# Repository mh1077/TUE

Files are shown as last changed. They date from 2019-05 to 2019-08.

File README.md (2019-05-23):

# TUE
Tochteruhrempfänger für MRClock

Dieser Empfänger verarbeitet die Multicast Telegramme eines MRClock Zeitzeichenservers. Aus einer LiPo Zelle (4.2 V) werden die 12 Volt bzw. 24 Volt für die Tochteruhren, auch Nebenuhren genannt, generiert und gleichzeitig der Empfänger (ESP8266) versorgt. Eine Ladeschaltung läd aus einer 5V Versorgung (USB oder Steckernetzteil) die LiPo Zelle.  

Eine Abschaltung bei niedriger LiPo Zellenspannung (ab ca. 3.1V) ist eingebaut. Der Empfänger behält die an der Tochteruhr angezeigte Uhrzeit gespeichert und läuft während dem Ladevorgang ab ca. 3.6V wieder los.

Ein TUE kann auch die Normalzeit mit NTP empfangen. Das funktioniert so. Wird ca. 6 Minuten nach der Konfiguration des Empfängers kein gültiges MRClock Telegramm empfangen, wird die Normalzeit angezeigt. Die Normalzeit wird auch angezeigt, wenn 24 Stunden kein gültiges MRClock Telegramm empfangen wurde. Es wird die MEZ mit automatischer Sommer-/Winterzeitumstellung angezeigt. Wird der Empfänger neu gestartet, sei es durch Reset oder Einschalten, wird nach ca. 6 Minuten auf NTP umgestellt wenn kein MRClock Telegramm empfangen wurde.

Das Projekt enthält die EAGLE Dateien, den Arduino Sourcecode und eine Bedienungsanleitung für den Tochteruhrempfänger.

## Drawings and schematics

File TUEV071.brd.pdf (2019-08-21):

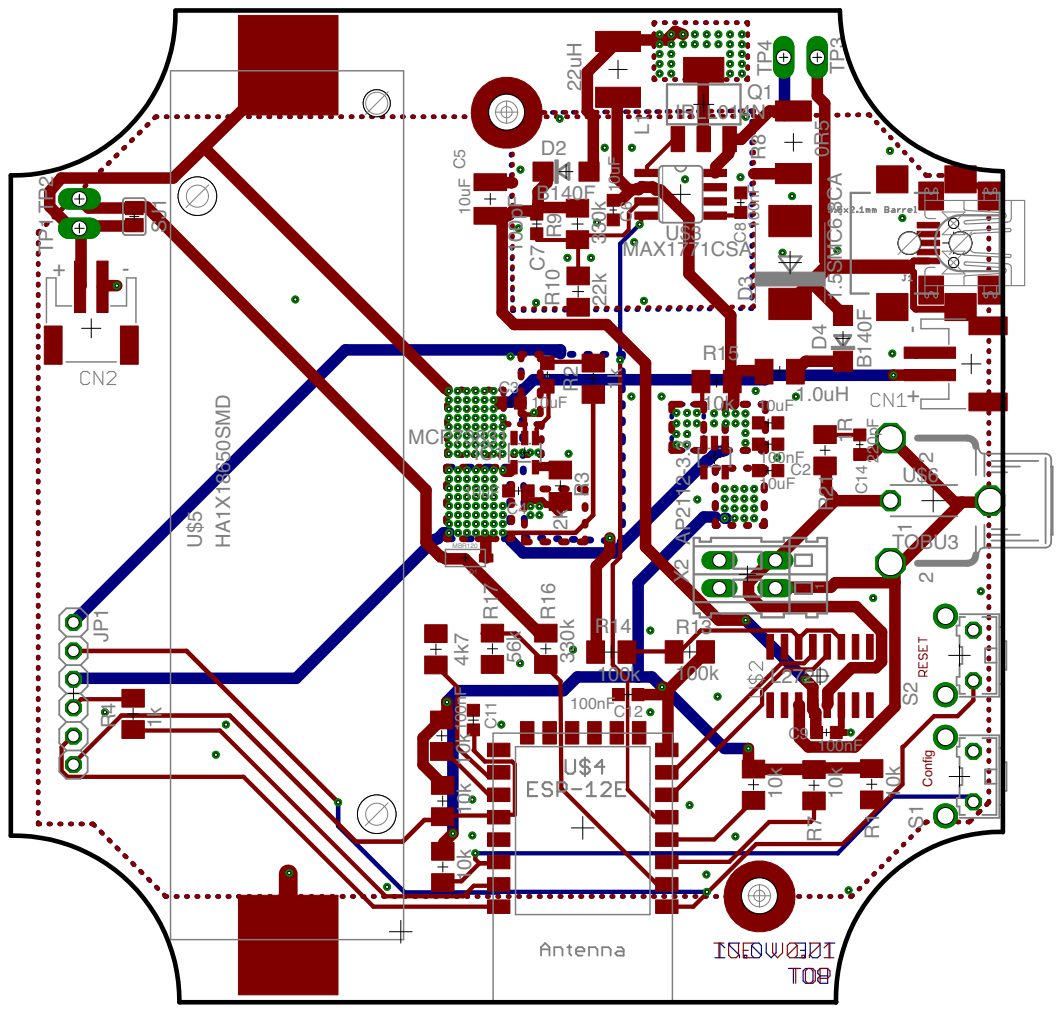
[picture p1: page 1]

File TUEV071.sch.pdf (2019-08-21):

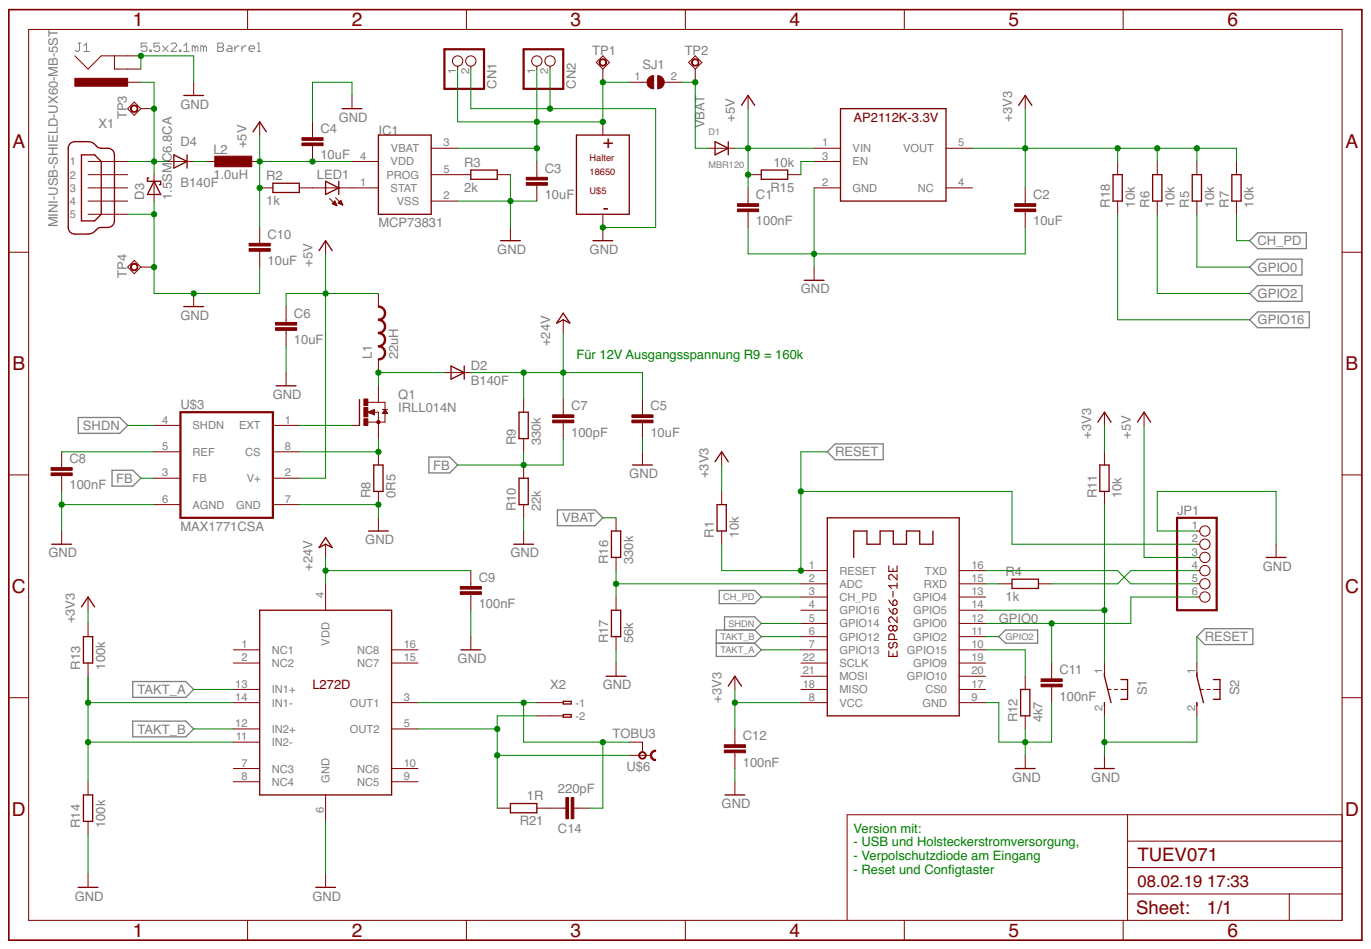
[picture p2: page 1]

MINI-USB-SHIELD-UX60-MB-5ST

Version mit: - USB und Holsteckerstromversorgung, - Verpolschutzdiode am Eingang - Reset und Configtaster

Sheet: 1/1

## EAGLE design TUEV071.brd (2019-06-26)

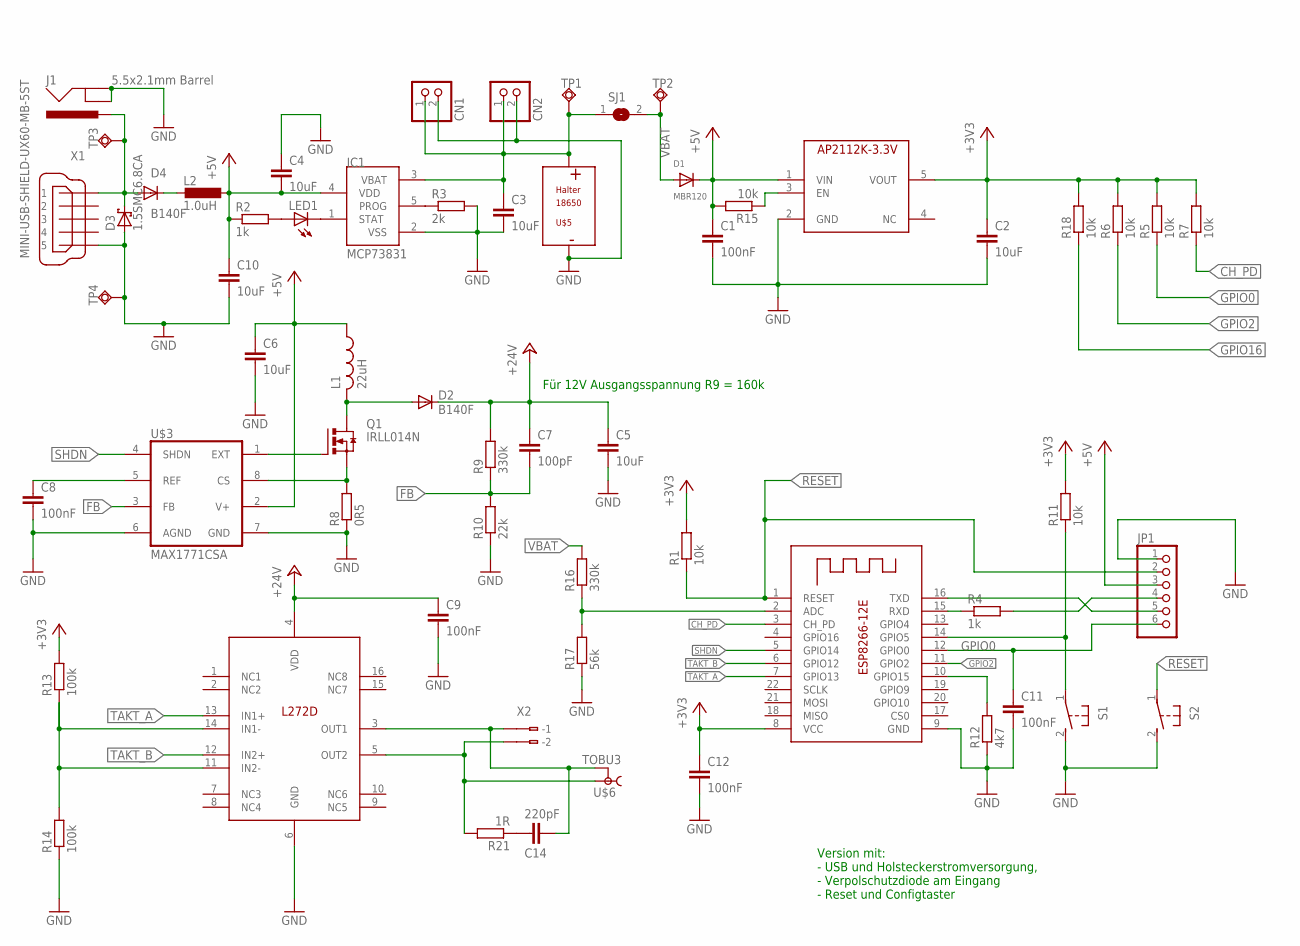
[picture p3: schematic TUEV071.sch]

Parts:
C1, C8, C9, C11, C12: 100nF; C0603K
C2, C3, C4, C6, C10: 10uF; C0603K
C5: 10uF; C1210K
C7: 100pF; C0603K
C14: 220pF; C0603K
CN1, CN2: JST_2PIN-SMT-RA; JST-PH-2-SMT-RA
D1: MBR120; SOD-123
D2, D4: B140F; DO214AC
D3: 1.5SMC6.8CA; SMC
IC1: MCP73831; SOT23-5L
J1: 5.5x2.1mm Barrel; POWER_JACK_SMD
JP1: PINHD-1X6; 1X06
L1: 22uH; L5650M
L2: 1.0uH; L3230M
LED1: LEDCHIPLED_0805; CHIPLED_0805
Q1: IRLL014N; SOT223
R1, R5, R6, R7, R11, R15, R18: 10k; M1206
R2, R4: 1k; M1206
R3: 2k; M1206
R8: 0R5; R2512
R9, R16: 330k; M1206
R10: 22k; M1206
R12: 4k7; M1206
R13, R14: 100k; M1206
R17: 56k; M1206
R21: 1R; M1206
S1, S2: 31-XX; B3F-31XX
SJ1: SJ
TP1, TP2, TP3, TP4: TPSQPAD1-13Y; P1-13Y
U$1: AP2112-3.3; SOT23-5L
U$2: L272D; SO16
U$3: MAX1771CSA; SO08
U$4: ESP-12E
U$5: HA1X18650SMD
U$6: TOBU3; TOBU3-REICHELT
X1: MINI-USB-SHIELD-UX60-MB-5ST; UX60-MB-5ST
X2: 233-102

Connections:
+3V3: C2.1, C12.1, R1.2, R5.2, R6.2, R7.2, R11.2, R13.2, R18.2, U$1.5 (VOUT), U$4.8 (VCC)
+5V: C1.1, C4.2, C6.1, C10.1, D1.C, IC1.4 (VDD), JP1.3, L1.1, L2.1, R2.1, R15.2, U$1.1 (VIN), U$3.2 (V+)
+24V: C5.1, C7.1, C9.1, D2.C, R9.2, U$2.4 (VDD)
CH_PD: R7.1, U$4.3 (CH_PD)
FB: C7.2, R9.1, R10.2, U$3.3 (FB)
GND: C1.2, C2.2, C3.2, C4.1, C5.2, C6.2, C8.2, C9.2, C10.2, C11.2, C12.2, CN1.2 (1), CN2.2 (1), D3.A, IC1.2 (VSS), J1.GND (GNDBREAK), J1.P$4 (GND), JP1.1, R3.2, R8.1, R10.1, R12.1, R14.1, R17.1, S1.2 (S), S2.2 (S), TP4.TP, U$1.2 (GND), U$2.6 (GND), U$3.6 (AGND), U$3.7 (GND), U$4.9 (GND), U$5.P$2-, X1.5
GPIO0: C11.1, JP1.6, R5.1, U$4.12 (GPIO0)
GPIO2: R6.1, U$4.11 (GPIO2)
GPIO16: R18.1
unnamed: JP1.5, U$4.16 (TXD)
unnamed: JP1.4, R4.2
unnamed: R4.1, U$4.15 (RXD)
unnamed: IC1.1 (STAT), LED1.C
unnamed: LED1.A, R2.2
unnamed: IC1.5 (PROG), R3.1
unnamed: Q1.1 (G), U$3.1 (EXT)
unnamed: D4.C, L2.2
unnamed: Q1.3 (S), R8.2, U$3.8 (CS)
unnamed: D2.A, L1.2, Q1.2 (D), Q1.4 (D)
unnamed: C14.2, U$2.3 (OUT1), U$6.2, U$6.2@1 (2), U$6.2@2 (2), X2.B1 (B-1)
unnamed: C8.1, U$3.5 (REF)
unnamed: R21.2, U$2.5 (OUT2), U$6.1, X2.B2 (B-2)
unnamed: R12.2, U$4.10 (GPIO15)
unnamed: D3.C, D4.A, J1.VIN0 (PWR), TP3.TP, X1.1
unnamed: R16.1, R17.2, U$4.2 (ADC)
unnamed: R15.1, U$1.3 (EN)
unnamed: C14.1, R21.1
unnamed: R11.1, S1.1, U$4.14 (GPIO5)
unnamed: R13.1, R14.2, U$2.11 (IN2-), U$2.14 (IN1-)
RESET: JP1.2, R1.1, S2.1, U$4.1 (RESET)
SHDN: U$3.4 (SHDN), U$4.5 (GPIO14)
TAKT_A: U$2.13 (IN1+), U$4.7 (GPIO13)
TAKT_B: U$2.12 (IN2+), U$4.6 (GPIO12)
VBAT: D1.A, R16.2, SJ1.2, TP2.TP
VBAT1: C3.1, CN1.1 (2), CN2.1 (2), IC1.3 (VBAT), SJ1.1, TP1.TP, U$5.P$1+

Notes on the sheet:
Für 12V Ausgangsspannung R9 = 160k
Version mit: - USB und Holsteckerstromversorgung, - Verpolschutzdiode am Eingang - Reset und Configtaster

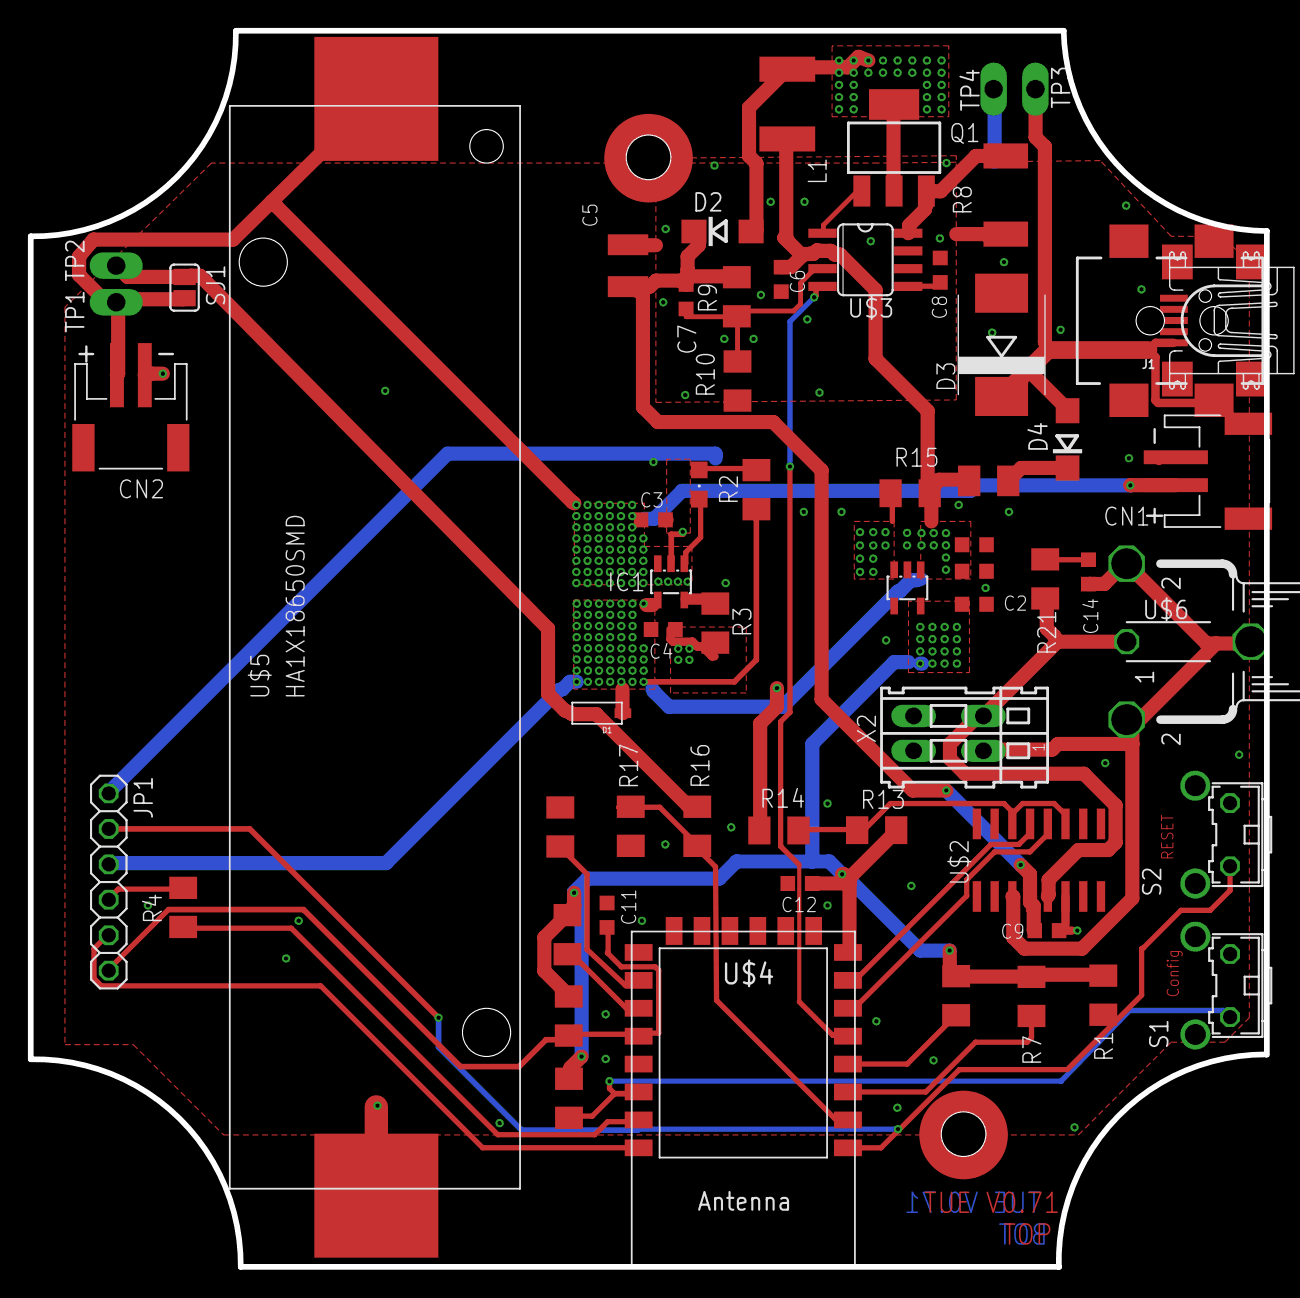
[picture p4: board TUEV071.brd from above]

Board: 2 copper layers, 88.6 x 88.6 mm, 60 parts (0 on the bottom side), 34 nets.

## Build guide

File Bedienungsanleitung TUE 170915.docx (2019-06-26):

Bedienungsanleitung

Tochteruhrempfänger

TUE

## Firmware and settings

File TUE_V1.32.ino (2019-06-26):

//Lauffähig ab LP Stand 0.51
//Ein-taster auf GPIO16-RST und Ausfunktion am Config Schalter
//hoe 10.03.17
//hoe 1.6.17 V1.2 Mit NTP Funktion, sobald ein ntp server eingetragen wurde, wird versucht die aktuelle Zeit mit NTP abzufragen und die Uhr danach zu stellen. 
//           wird jedoch ein MRCLOCK Telegramm empfangen, wird der NTP Empfang um die Wartezeit WaittimeNTPSync unterdrückt, MRCLOCK Empfang hat vorrang vor NTP!
//           als Zeitzone wird standardmässig MEZ mit Sommerzeit eingestellt.
//hoe 15.8.17 V1.3 Abgabeversion mit Entladespannung des Akkus bei 3.1V; Start nachdem Akku 3.6V erreicht hat. Systemwechselzeit MRClock -> NTP = 24h
//hoe 30.12.17 V1.3.1 kleinere Korrekturen (Rechtschreibung)
//hoe 10.03.18 V1.3.2 längere Taktpause beim Stellen eingebaut, damit auch grössere Uhren nachkommen. (Nach test vom Treffen Mammendorf 2017) war Taktpause war 500ms, jetzt 1000ms

#define VERSION "V1.3.2"

#include <FS.h>                   //this needs to be first, or it all crashes and burns...

#include <TickerScheduler.h>      //Ticker

#include <ESP8266WiFi.h>          //https://github.com/esp8266/Arduino

//needed for library
#include <ESP8266WebServer.h> 
#include <WiFiManager.h>          //https://github.com/tzapu/WiFiManager

#include <ArduinoJson.h>          //https://github.com/bblanchon/ArduinoJson

//needed for NTP 
#include <TimeLib.h>
#include <WiFiUdp.h>
#include <Timezone.h> //by Jack Christensen, not included in the Arduino IDE !!!

//Defines for Pins

#define CHARGEPUMPENABLE 14       //SPI SCK = GPIO #14 (Charge Pump enable)
#define TAKTA            13       //SPI MOSI = GPIO #13 (TaktA)
#define TAKTB            12       //SPI MISO = GPIO #12 (TaktB)
#define CONFIGPB          5       //GPIO #5 (Input für Config Pushbutton) Bei MRC_REC = 16!
#define BLED              2       //GPIO #2 = blue LED on ESP
#define INT               4       //GPIO #4 = Interrupt für Spannungseinbruch -> Interrupt wird an der fallenden Flanke ausgelöst

//defines für Zeiten
#define TAKTTIME          10      //Wie lange wird der Stelltakt ausgegeben? 1 Einheit entspricht 10 ms Taktausgabezeit
#define TAKTWAITIME       100      //So lange darf kein Takt ausgegeben werden     
#define CHARGEPUMPTIME    2       //So lange wird auf die Chargepump gewartet
#define WaittimeNTPSync   1440000 //Zeit in ms bis von MRCLOCK Telegrammempfang auf NTP umgeschalten wird. 1440000 entspricht 24h
#define WaittimeNTP1Sync  36000   //Zeit in 10ms. Uhr stellt sich nach der Configroutine auf NTP um, sofern kein MRCLOCK Telegramm empfangen wurde. 36000 entsprechen 6 Minuten

//defines für den LED Status
#define LEDOff            0       //LED is off
#define LEDBlinking       1       //Flashing LED (Saving Time to Flash)
#define LEDAlive          2       //TUE is alive
#define LEDConfig         3       //TUE is in Config mode
#define LEDOn             5       //LED is on
#define LEDBlinkOnce      6       //LED macht einen Blinker
#define LEDAusVorbereitet 7       //LED macht langsamen Blinkrythmus

int LEDStatus = 0;                //LED Status wird durch das Programm gemäss den oben angegebenen Defines gesetzt und durch die Task LED() wird die LED angesteuert
int LEDStatusIntern = 0;          //LED Status intern für die LED Routine
int LEDStatusCounter = 0;         //LED Status Counter zum zählen bis zum nächsten Statuswechsel
int LEDPeriodCounter = 0;         //Dient als Zähler für das Aus vorbereitet....

#define LEDalivetime      1
#define LEDalivecycle     1000    //LED alive = jede 10s ein kurzer blauer blitz
#define LEDblinkingcycle  5
#define LEDAusVorbtime    2
#define LEDAusVorbcycle   5
#define LEDAusVorbperiod  1000
       
//define your default values here, if there are different values in config.json, they are overwritten.
char mrc_multicast[40] = "239.50.50.20";
char mrc_port[6] = "2000";

//char array for the protokollhandler 
char c_clock_hour[15] = "03";
char c_clock_minute[15] = "02";
char c_clock_sek[15] = "04";
char c_time[15] = "0";
char c_speed[15] = "0";

//Strings 
String esp_chipid;

//ADC Daten
int  adcwert;                   //Aktueller ADC Wert
int  adcmittelwert;             //Mittelwert
bool fESPrunning = true;        //Flag spiegelt den Zustand des ESP wieder true bedeutet genügend VCC, false = ESP ruht
bool fDataSaving = false;       //Die Daten müssen ins Flash gespeichert werden, der ESP hat zuwenig Spannung

#define adcstopgrenzwert  440         //ab diesem ADC Wert schaltet der ESP ab und zirkuliert in einer Warteschleife bis adc > adcstart 440 entspricht ca. 3.12 V
#define adcstartgrenzwert 499         //ab diesem ADC Wert schaltet der ESP wieder ein
#define adcconnectedio    300         //falls der adc beim Starten mehr als diesen Wert liest, gilt der adc als verdrahtet und wird benutzt

//Daten aus dem Protokoll
int  clock_h = 0;   // Sollzeit Stunde
int  clock_m = 0;   // Sollzeit Minute
int  clock_s = 0;   // Sollzeit Sekunde
int  clock_speed = 1; // 

int  tochter_h = 0; // Istzeit auf der 12h Tochteruhr (Stunden)
int  tochter_m = 0; // Istzeit auf der 12h Tochteruhr (Minuten)

//NTP Variablen
char ntpserver[40] = "ntp.metas.ch";         //NTPServer
unsigned int localPort = 8888;               // local port to listen for UDP packets
const int timeZone = 0;                      // UTC
double dCounterToNTP;                        //if no MRCLOCK telegramm is recieved, the conter gets decressed, on ZERO the NTP time is displayed

//Timezone
//Central European Time (Frankfurt, Paris)
TimeChangeRule CEST = { "CEST", Last, Sun, Mar, 2, 120 };     //Central European Summer Time
TimeChangeRule CET = { "CET ", Last, Sun, Oct, 3, 60 };       //Central European Standard Time
Timezone CE(CEST, CET);
TimeChangeRule *tcr;        //pointer to the time change rule, use to get the TZ abbrev
time_t utc, local;
time_t prevDisplay = 0;     // when the digital clock was displayed

//Statemaschine für TochterUhrStellen Routine
int  SM = 0;        // Statemaschine Status
int  SMC = 0;       // Statemaschine Counter
bool FlagTUStellen = false;          // Flag ist gesetzt, falls die Tochteruhr einen Tick machen soll
bool FlagTUStellglied;               // Flag wiederspiegelt den Ausgang des TU Stellglieds

//Rücksetztaste
bool FlagButtonPresed = false;
int  CounterButtonPressed;

//Tickerscheduler Objekt

TickerScheduler ts(6);

//flag for saving data
bool shouldSaveConfig = false;

//flag for sleep mode 
bool sleep = false;
bool flag_message_recieved = true;

//WifiUDP Class
WiFiUDP wifiUDPMRC;    //für MRClock Telegramme
WiFiUDP wifiUDPNTP;    //für NTP Telegramme

const int MRC_PACKET_SIZE = 2024; // NTP time stamp is in the first 48 bytes of the message

char packetBuffer[ MRC_PACKET_SIZE ]; //buffer to hold incoming and outgoing packets

int nLength = 0;

int time_hour = 0;

int time_minute = 0;

//WiFiManager
  //Das Object wird auch noch im LOOP benötigt um die Config zu löschen.... 
  WiFiManager wifiManager;
  //Die beiden Parameter werden durch ein Callback verändert, deswegen müssen sie Global definiert sein
  WiFiManagerParameter custom_time_hour();
  WiFiManagerParameter custom_time_minute();

//callback notifying us of the need to save config
void saveConfigCallback () {
  Serial.println("Should save config");
  shouldSaveConfig = true;
}

// CALLBACK wird mit dem Starten der Configurationsseite aufgerufen und stellt die Uhr um zwei Ticks weiter, damit sie mit der internen Uhr synchron läuft
void APCallback(WiFiManager *myWiFiManager){
  
  forcetick();
 
  while(FlagTUStellen){
    yield();
    ts.update();
    Serial.print(".");
    delay(10);
  }
  
  forcetick();
  
  while(FlagTUStellen){
    yield();
    ts.update();
    Serial.print(".");
    delay(10);
  }
  
  WiFiManagerParameter custom_time_hour("clock_hour", "zulaessige Werte (00-11)", c_clock_hour, 15);
  WiFiManagerParameter custom_time_minute("clock_minute", "zulaessige Werte (00-59)", c_clock_minute, 15);
}

void setup() {
  // put your setup code here, to run once:
  Serial.begin(115200);
  Serial.println();

  LED(LEDOff);               // Am Anfang ist die LED aus....

  //ChipID?
  esp_chipid = String(ESP.getChipId());

  //Identify
  Serial.print("Tochteruhrempfänger TUE ");
  Serial.print(VERSION);
  Serial.print(" ESP - ChipID = ");
  Serial.println(esp_chipid); 

  Serial.println("Configuring Pins and Interrupts");

  //WiFi.setAutoReconnect(false);
  WiFi.persistent(true); // Wird gebraucht damit das Flash nicht zu oft beschrieben wird.
  WiFi.setAutoReconnect(true);

  //Pins konfigurieren
  //SPI SCK = GPIO #14 (Charge Pump enable)
  //SPI MOSI = GPIO #13 (TaktA)
  //SPI MISO = GPIO #12 (TaktB)
  //GPIO #5 (Input für Config Pushbutton)
  //GPIO #16 for Enable and Battery Saving :-)
  //GPIO #2 = blue LED on ESP
  //GPIO #9 = Überwachung der Versorgungsspannung

  pinMode(TAKTA, OUTPUT);
  pinMode(TAKTB, OUTPUT);
  pinMode(CHARGEPUMPENABLE, OUTPUT);
  pinMode(CONFIGPB, INPUT);
  pinMode(BLED, OUTPUT);
  
  digitalWrite(CHARGEPUMPENABLE, HIGH); 
  digitalWrite(BLED, HIGH);
  
  ts.add(4, 10, LEDTS);

  LED(LEDBlinkOnce);         // LED einen Flash blinken -> 1. Blinkimpuls

  //clean FS, for testing
  //SPIFFS.format();
  //SPIFFS.remove("/config.json");
  //SPIFFS.remove("/config2.json");
  
  //read configuration from FS json
  Serial.println("mounting FS...");

  // Falls das Filesystem noch nicht formatiert ist, wird es hier automatisch gemacht.
  if(SPIFFS.begin()){
    Serial.println("FS ok!");
  } else {
    SPIFFS.format();
    Serial.println("FS formated");
  }

  LED(LEDBlinkOnce);     // LED einen Flash blinken  -> 2. Blinkimpuls
  
  if (SPIFFS.begin()) {
    Serial.println("mounted file system");
    if (SPIFFS.exists("/config.json")) {
      //file exists, reading and loading
      Serial.println("reading config file");
      File configFile = SPIFFS.open("/config.json", "r");
      if (configFile) {
        Serial.println("opened config file");
        size_t size = configFile.size();
        // Allocate a buffer to store contents of the file.
        std::unique_ptr<char[]> buf(new char[size]);

        configFile.readBytes(buf.get(), size);
        DynamicJsonBuffer jsonBuffer;
        JsonObject& json = jsonBuffer.parseObject(buf.get());
        json.printTo(Serial);
        if (json.success()) {
          Serial.println("\nparsed json");
          strcpy(ntpserver, json["ntp_server"]);
          strcpy(mrc_multicast, json["mrc_multicast"]);
          strcpy(mrc_port, json["mrc_port"]);
          strcpy(c_clock_hour, json["clock_hour"]);
          strcpy(c_clock_minute, json["clock_minute"]);
          if(json["FlagTUStellglied"] == "true"){
            FlagTUStellglied = true;
            digitalWrite(TAKTA, LOW);
            digitalWrite(TAKTB, LOW);
            Serial.print("FlagTUStellglied = true");
          }else{
            FlagTUStellglied = false;
            digitalWrite(TAKTA, HIGH);
            digitalWrite(TAKTB, HIGH); 
            Serial.print("FlagTUStellglied = false");
          }
        } 
      }
    }
  } else {
    Serial.println("failed to mount FS");
    FlagTUStellglied = true;
    digitalWrite(TAKTA, LOW);
    digitalWrite(TAKTB, LOW);
    Serial.println("failed to load json config");
  }
  //end read

  //Interne Zeit mit der Tochteruhrzeit gleich setzen, sonst läuft uns die Uhr nach einem Neustart los...
  tochter_h = atoi(c_clock_hour);
  tochter_m = atoi(c_clock_minute);

  sprintf(c_clock_hour, "%i", tochter_h);
  sprintf(c_clock_minute, "%i", tochter_m);

  Serial.print("Tochteruhr zeigt ");
  Serial.print(tochter_h);
  Serial.print(":");
  Serial.print(tochter_m);
  Serial.println(" an.");

  // The extra parameters to be configured (can be either global or just in the setup)
  // After connecting, parameter.getValue() will get you the configured value
  // id/name placeholder/prompt default length
  WiFiManagerParameter custom_text_info1("<br>Einstellmen&uuml; f&uuml;r den Tochteruhrempf&auml;nger.<br>");
  WiFiManagerParameter custom_text_info2("Empf&auml;ngt Zeitzeichentelegramme nach dem MRClock Protokoll.<br><br>");
  WiFiManagerParameter custom_text_info3("Standarteinstellung MRClock: Multicast 239.50.50.20 auf Port 2000.<br>Bitte nur die Stellung der Nebenuhr anpassen. Die anderen Einstellungen m&uuml;ssen meistens nicht ge&auml;ndert werden.<br>");
  WiFiManagerParameter custom_text_h("Stand der Nebenuhr, hier Stunden (ganze Zahl von 0 bis 11):");
  WiFiManagerParameter custom_text_m("Stand der Nebenuhr, hier Minuten (ganze Zahl von 0 bis 59):");
  WiFiManagerParameter custom_text_expert("<br>Ab hier Experteneinstellungen, nur &auml;ndern wenn wann weiss was man macht!<br>");
  WiFiManagerParameter custom_text_multicast_adress("Empfangsadresse der MRClock Telegramme:");
  WiFiManagerParameter custom_mrc_multicast("mrc_multicast", "mrc_multicast (239.50.50.20)", mrc_multicast, 40);
  WiFiManagerParameter custom_text_multicast_port("Empfangsport der MRClock Telegramme:");
  WiFiManagerParameter custom_mrc_port("mrc_port", "mrc_multicast_port (2000)", mrc_port, 5);
  WiFiManagerParameter custom_text_ntpserver("<br>Zeitserver zum Synchronisieren auf die MEZ:");
  WiFiManagerParameter custom_ntp_server("NTP_Server", "ntp.server.de", ntpserver, 40);
  WiFiManagerParameter custom_time_hour("clock_hour", "zul&auml;ssige Werte (00-11)", c_clock_hour, 15);
  WiFiManagerParameter custom_time_minute("clock_minute", "zul&auml;ssige Werte (00-59)", c_clock_minute, 15);

  //set config save notify callback
  wifiManager.setSaveConfigCallback(saveConfigCallback);

  //set APCallback
  wifiManager.setAPCallback(APCallback);
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
void loop() {
  // loop checks for:
  // - MRCLOCK Telegramm, or
  // - NTP 
  // MRCLOCK has priority to NTP telegramms, if there were no MRCLOCK Telegramm for WaittimeNTPSync [seconds] then, the 
  // Slaveclock is syncronised to NTP Clock until the first MRCLOCK telegramm comes in...
  // If a MRCLOCK Telegramm is recieved:
  if (int packetsize = wifiUDPMRC.parsePacket()) {
    dCounterToNTP = WaittimeNTPSync;           // Counter updaten
    Serial.println("@.");
    // We've received a packet, read the data from it
    wifiUDPMRC.read(packetBuffer, packetsize); // read the packet into the buffer

    //Search for Message like "clock=10:32:35"
    for(int i=0; i < sizeof(packetBuffer); i++){
       if( packetBuffer[i] == 'c' &&
           packetBuffer[i+1] == 'l' &&
           packetBuffer[i+2] == 'o' &&
           packetBuffer[i+3] == 'c' &&
           packetBuffer[i+4] == 'k' &&
           packetBuffer[i+5] == '='){
            c_time[0] = packetBuffer[i+6];
            c_time[1] = packetBuffer[i+7];
            c_time[2] = packetBuffer[i+8];
            c_time[3] = packetBuffer[i+9];
            c_time[4] = packetBuffer[i+10];
            c_time[5] = packetBuffer[i+11];
            c_time[6] = packetBuffer[i+12];
            c_time[7] = packetBuffer[i+13];
            c_time[8] = packetBuffer[i+14];
            
            // Time Char Array zerlegen
            bool clear_h = true;
            bool clear_m = false;
            bool clear_s = false;
            
            for(int ii=0; ii < 15; ii++){
              if( !clear_h && !clear_m && clear_s){                
                if( c_time[ii] == 0){
                  clear_m = false;
                  clear_s = false;
                  c_clock_hour[ii] = ' ';
                  c_clock_minute[ii] = ' ';
                  c_clock_sek[ii] = ' ';
                }else{
                  c_clock_hour[ii] = ' ';
                  c_clock_minute[ii] = ' ';
                  c_clock_sek[ii] = c_time[ii];
                }
              }
              if( !clear_h && clear_m && !clear_s){                
                if( c_time[ii] == ':'){
                  clear_m = false;
                  clear_s = true;
                  c_clock_hour[ii] = ' ';
                  c_clock_minute[ii] = ' ';
                  c_clock_sek[ii] = ' ';
                }else{
                  c_clock_hour[ii] = ' ';
                  c_clock_minute[ii] = c_time[ii];                  
                  c_clock_sek[ii] = ' ';
                }
              }
              if( clear_h && !clear_m && !clear_s){                
                if( c_time[ii] == ':'){
                  clear_h = false;
                  clear_m = true;
                  c_clock_hour[ii] = ' ';
                  c_clock_minute[ii] = ' ';
                  c_clock_sek[ii] = ' ';
                }else{
                  c_clock_hour[ii] = c_time[ii];
                  c_clock_minute[ii] = ' ';
                  c_clock_sek[ii] = ' ';
                }
              }
            }
  
            clock_h = atoi(c_clock_hour);
            clock_m = atoi(c_clock_minute);
            clock_s = atoi(c_clock_sek);

            Serial.print("Empfangenes Zeitzeichen:");
            Serial.print(clock_h);
            Serial.print(":");
            Serial.print(clock_m);
            Serial.print(":");
            Serial.println(clock_s);
         }
     }
     //Search for Message like "speed=5"
     for(int i=0; i < sizeof(packetBuffer); i++){
       if( packetBuffer[i] == 's' &&
           packetBuffer[i+1] == 'p' &&
           packetBuffer[i+2] == 'e' &&
           packetBuffer[i+3] == 'e' &&
           packetBuffer[i+4] == 'd' &&
           packetBuffer[i+5] == '='){
            if(packetBuffer[i+6] != 32){
              c_speed[0] = packetBuffer[i+6];
            }
            if(packetBuffer[i+7] != 32){
              c_speed[1] = packetBuffer[i+7];
            }
            if(packetBuffer[i+8] != 32){
              c_speed[2] = packetBuffer[i+8];
            }
            if(packetBuffer[i+9] != 32){
              c_speed[3] = packetBuffer[i+9];
            }
            c_speed[4] == NULL;

            Serial.println("Speed=");
            Serial.println(c_speed);
  
            clock_speed = atoi(c_speed);
            
            Serial.println(clock_speed);
         }
      }

      // recieving one message!
      Serial.println("; Ende der Message");
      flag_message_recieved = true;
  }
  

  // Ist der Taster gedrückt?
  ConfigButton();

  // Haben wir noch Saft?
  if(fDataSaving){
    DataSaving();
    fDataSaving = false;
  }
  
  while(!fESPrunning){    //While schleife solange wir keine Betriebsspannung haben
    //Tasks bedienen
    LEDStatus = LEDOff;   //LED aus
    yield();
    ts.update();
    Serial.print("s");
    LEDTS();
    delay(1000);

    // Haben wir noch Saft?
    if(fDataSaving){
      DataSaving();
      fDataSaving = false;
    }
    
    // ChargePump abschalten
    digitalWrite(CHARGEPUMPENABLE, HIGH);
    //ESP abschalten   
    ESP.deepSleep(10);
    delay(1000);
  } 

  //Soll auf NTP-Zeitzeichenempfang umgeschaltet werden?
  if(dCounterToNTP == 0){
    //jetzt wird die NTP Zeit an der Tochteruhr angezeigt...
    if (timeStatus() != timeNotSet) {
      if (now() != prevDisplay) { //update the display only if time has changed
        prevDisplay = now();

        local = CE.toLocal(now(), &tcr);
        
        Serial.print("Hour=");
        Serial.print(hour(local), DEC);
        Serial.print("Minute=");
        Serial.print(minute(local), DEC);
        Serial.print("Seconds=");
        Serial.println(second(local), DEC);
  
        clock_h = hour(local);
        clock_m = minute(local);
        clock_s = second(local);
      }
    }
  }else dCounterToNTP--;

  //Tasks bedienen
  yield();
  ts.update();
  Serial.print(".");
  delay(10);
}

//Task zum weiterstellen der Tochteruhr
//Wird zyklisch aufgerufen und prüft, ob die empfangene Uhrzeit mit der angezeigten Uhrzeit übereinstimmt. 
//Stellt sie einen Unterschied fest, setzt sie das Flag "FlagTUStellen", dieses Flag wird durch die Task "TochterUhrStellen" 
//ausgewertet, bearbeitet und zurückgestellt.
//Task verwaltet die Uhrzeit der Tochteruhr.
void * tick(){  
  if( !FlagTUStellen ){
    // Zeitzeichen mit Tochteruhr vergleichen, die Tochteruhr ist eine 12h Uhr. Das Zeitzeichen kann auch im 24h gesendet werden.
    if( ( clock_h == tochter_h && clock_m == tochter_m ) || ( clock_h-12 == tochter_h && clock_m == tochter_m ) ){
      // Tochteruhr stimmt mit Zeitzeichen überein, nix machen
    } else {
      // Tochteruhr muss gestellt werden.
      tochter_m++;
      if (tochter_m == 60){ // Stundensprung
        tochter_h++;
        tochter_m = 0;
        if (tochter_h == 12){ // Tagesprung
          tochter_h = 0;
        }
      }
      FlagTUStellen = true;
      Serial.print("Tochteruhr stellt auf Zeit=");
      Serial.print(tochter_h);
      Serial.print(":");
      Serial.print(tochter_m);
      Serial.print(" Zeitzeichen=");
      Serial.print(clock_h);
      Serial.print(":");
      Serial.print(clock_m);
      Serial.print(":");
      Serial.println(clock_s);
    }
  }
}

//Task zum gezwungenen Weiterstellen der Tochteruhr
//Wird durch das Captive Portal aufgerufen und stellt sicher, dass die angeschlossene Tochteruhr 
//synchron zum internen Stellglied läuft.
//FlagTUStellen muss false sein, beim Aufruf der Routine, sonst keine Auswirkung.
void * forcetick(){  
  if( !FlagTUStellen ){
    // Tochteruhr muss gestellt werden.
    tochter_m++;
    if (tochter_m == 60){ // Stundensprung
      tochter_h++;
      tochter_m = 0;
      if (tochter_h == 12){ // Tagesprung
        tochter_h = 0;
      }
    }      
    FlagTUStellen = true;
    Serial.print("Tochteruhr stellt auf Zeit=");
    Serial.print(tochter_h);
    Serial.print(":");
    Serial.print(tochter_m);
    Serial.print(" Zeitzeichen=");
    Serial.print(clock_h);
    Serial.print(":");
    Serial.print(clock_m);
    Serial.print(":");
    Serial.println(clock_s);
  }
}


void * TochterUhr(){
  Serial.print("Tochteruhr zeigt=");
  Serial.print(tochter_h);
  Serial.print(" : ");
  Serial.print(tochter_m);
  Serial.println(" ");
}
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

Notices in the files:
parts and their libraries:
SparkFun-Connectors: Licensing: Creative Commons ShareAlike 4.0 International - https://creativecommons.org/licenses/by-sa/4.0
